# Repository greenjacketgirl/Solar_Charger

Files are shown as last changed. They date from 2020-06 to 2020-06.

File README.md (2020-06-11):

# Solar Charger Project

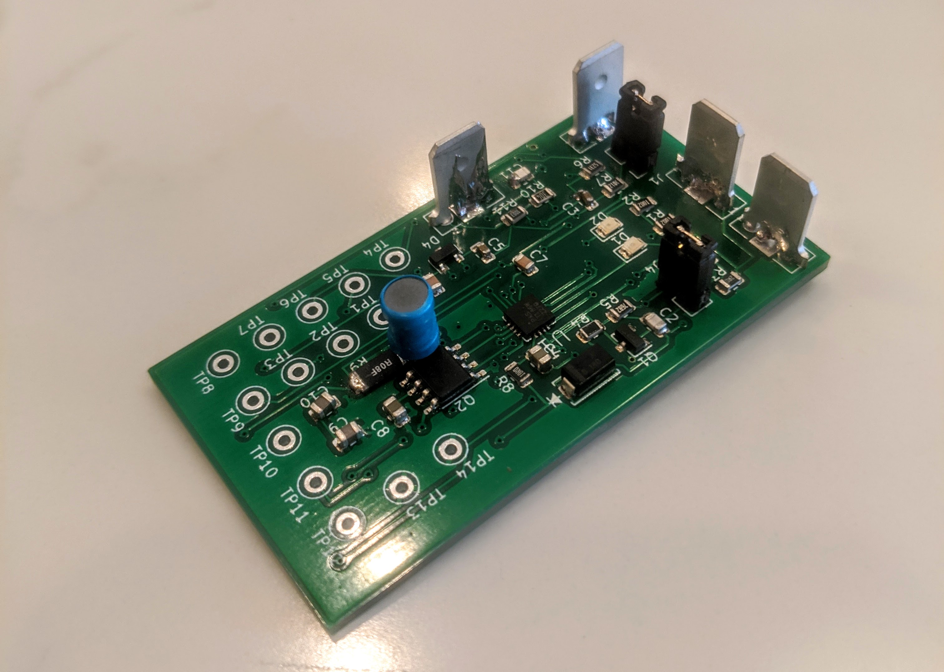
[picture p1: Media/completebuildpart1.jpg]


**Introduction** | This project was done in fullfillment of the requirments for Walla Walla University's Power Electronics class (ENGR 460) taught by [Dr. Rob Frohne](https://github.com/frohro). I chose to use Texas Instruments' BQ24650 integrated circuit as the voltage regular between a 11V solar panel and 2s 7.4V lipo. The aim was for the solar panel to charge the lipo battery at 0.5A so as to charge the battery at a standard pace while keeping the pace slow enough that the battery would not be damaged. For more details on the theory used by the charger IC, design specifications, user manual, and more - please reference the [Wiki](https://github.com/greenjacketgirl/Solar_Charger/wiki).

**Navigation** |This repository has content in the [Code](https://github.com/greenjacketgirl/Solar_Charger), [Issues](https://github.com/greenjacketgirl/Solar_Charger/issues), and [Wiki](https://github.com/greenjacketgirl/Solar_Charger/wiki) tabs.The Code section has 1 primary folder - "Solar-Charger" which contains two other folders, "Documentation" and "Kicad". The documentation folder contains stepping stone write ups and research on topics related to the issue as well as my power point presentation on the project. The Kicad folder contains the kicad files, revisions 1 and 2. Note the revisions when you are referencing them. The Wiki page contains the bulk of the documentation for this project which includes, but is not limited to the results, pcb and schematic design motives, specifiations, and objectives for the project. 

**Credits** | This project was chosen and directed by myself. However, I had professional support from my professor [Dr. Rob Frohne](https://github.com/frohro) as well as assistance from the application engineeers at texas instruments. 

**Project Status** | At the current time, the project does not fully work. While the charger circuit does not have any fried or damaged components, it does not charge the lipo battery. The STAT 1 LED turns on, indicating "charging in progress", but no charging has taken place from what I could deduce. See the [Issues](https://github.com/greenjacketgirl/Solar_Charger/issues) page for updates on current bugs.

REV 1: 05/26/2020 Build and Test Stage PART 1 | REV 2: 06/09/2020 Buil and Test Stage PART 2

***
page created by jordyn watkins | greenjacketgirl

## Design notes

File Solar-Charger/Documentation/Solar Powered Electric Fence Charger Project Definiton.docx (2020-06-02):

Solar Powered Electric Fence Charger

Project Definition: The aim of this class is to learn the basic methods of electric power analysis and design. To enforce this objective, I have chosen a project utilizing solar energy and a power switching mechanism — a solar powered electric fence charger. This project will be comprised of 2 major components:

1. Designing the solar panel voltage regulator circuit (solar to battery)
2. Designing the implementation of the electric fence (battery to fence)

The application of this project will be to provide protection for domestic animals such as chickens, from potential predators. The basic principle behind this project is using a solar panel to take in energy, which must be regulated before being directed to the input of the battery. The solar panel will be used to “top off” the charge in the battery. This battery, will then need to be attached to an inverter, which is then attached to a transformer to be bumped up to a few thousand volts (at low current levels) and modulated in pulses before transmission through the wire, thus creating an “electric fence.”

Block Diagram:

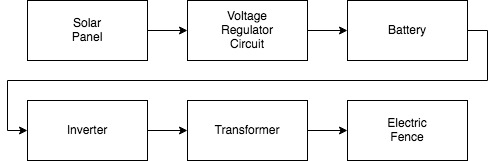
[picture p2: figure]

Upon further examination, the scope of this project definition appears to be too large. Consequently, I will be primarily focusing on the first 3 stages of this block diagram, using solar energy to maintain charge in a battery. If time permits, I will proceed to work on the last 3 blocks of the diagram, however, this remains an optional secondary goal.

A precise list of materials is yet to be determined as I develop a schematic for the voltage regulator circuit connecting the solar panel energy supply to the battery. However, a general list of parts with specifics to determine are:

- to what voltage will the energy from sunlight need to be regulated to in order to prevent damage to the battery? What minimum to charge it fully?
- What solar panel wattage/voltage will we be receiving?
- What size battery do we need to supply enough energy to the circuit/fence? 12V?
- What type of battery?
- What voltage do we need as an input to the transformer? 220V Ac?
- What voltage does our transformer need to output?
- Use of capacitors? Transistors? MOSFETS? Oscillators? Resistor Values?’ Transformer? Coils?

Resources:

http://chemelec.com/Projects/Fencer-1/Fencer-1.htm

https://www.pocketmagic.net/electric-fence-20kv/

https://www.backwoodshome.com/solar-powered-electric-fencing/

https://www.homemade-circuits.com/make-this-solar-powered-fence-charger/

https://www.homemade-circuits.com/how-to-make-solar-battery-charger/

https://www.homemade-circuits.com/how-to-build-solar-panel-voltage/

https://www.homemade-circuits.com/how-to-calculate-and-match-solar-panel/

https://www.homemade-circuits.com/how-to-make-solar-inverter-circuit/

https://gitlab.com/dakriy/solar-charger/-/wikis/theory

https://www.slideshare.net/Shubhamshekhar29/charging-of-battery-from-solar-supply-using-buck-boost-converter

https://krakkus.com/mppt-buck-boost-controller/

http://iallpowers.com/index.php?c=product&id=362

Parts List:

Lipo Battery Protection: BQ29707DSER (https://www.digikey.com/product-detail/en/texas-instruments/BQ29707DSER/296-39948-1-ND/5177825)

DataSheet: https://www.ti.com/lit/ds/symlink/bq2970.pdf

Digikey Link: https://www.digikey.com/product-detail/en/texas-instruments/BQ29707DSER/296-39948-1-ND/5177825

Cost: $0.67

MOSFET: DMG6968UDM-7

Datasheet: https://www.diodes.com/assets/Datasheets/ds31758.pdf

Digikey Link: https://www.digikey.com/product-detail/en/diodes-incorporated/DMG6968UDM-7/DMG6968UDMDICT-ND/2075462

Cost: $0.44

Boost Converter: RT4812GJ8F

Datasheet: https://www.richtek.com/assets/product_file/RT4812/DS4812-07.pdf

Digikey: https://www.digikey.com/product-detail/en/richtek-usa-inc/RT4812GJ8F/1028-1512-1-ND/5640521

Cost: $1.62

MPP: LT3652

Datasheet: https://www.analog.com/media/en/technical-documentation/data-sheets/3652fe.pdf

Digikey: https://www.digikey.com/product-detail/en/linear-technology-analog-devices/LT3652EMSE-PBF/LT3652EMSE-PBF-ND/2225686

Cost: $7.61

Jordyn WatkinsENGR460Project Definition & Research

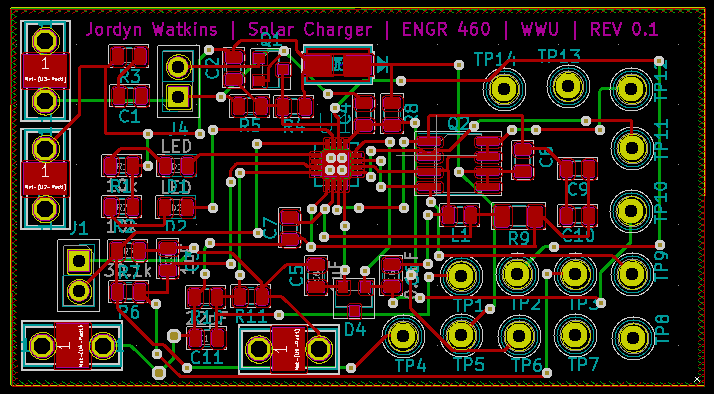
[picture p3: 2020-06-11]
Media/PCBdesign2D.png

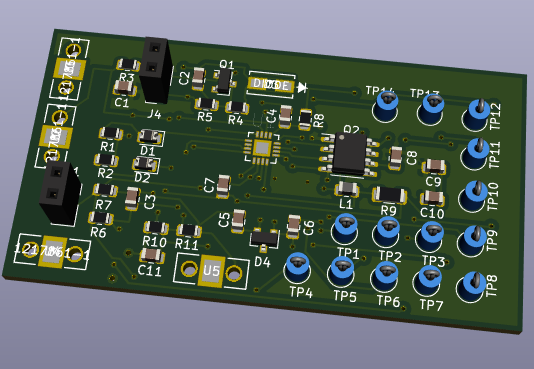
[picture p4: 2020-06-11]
Media/PCBDesign3D.png

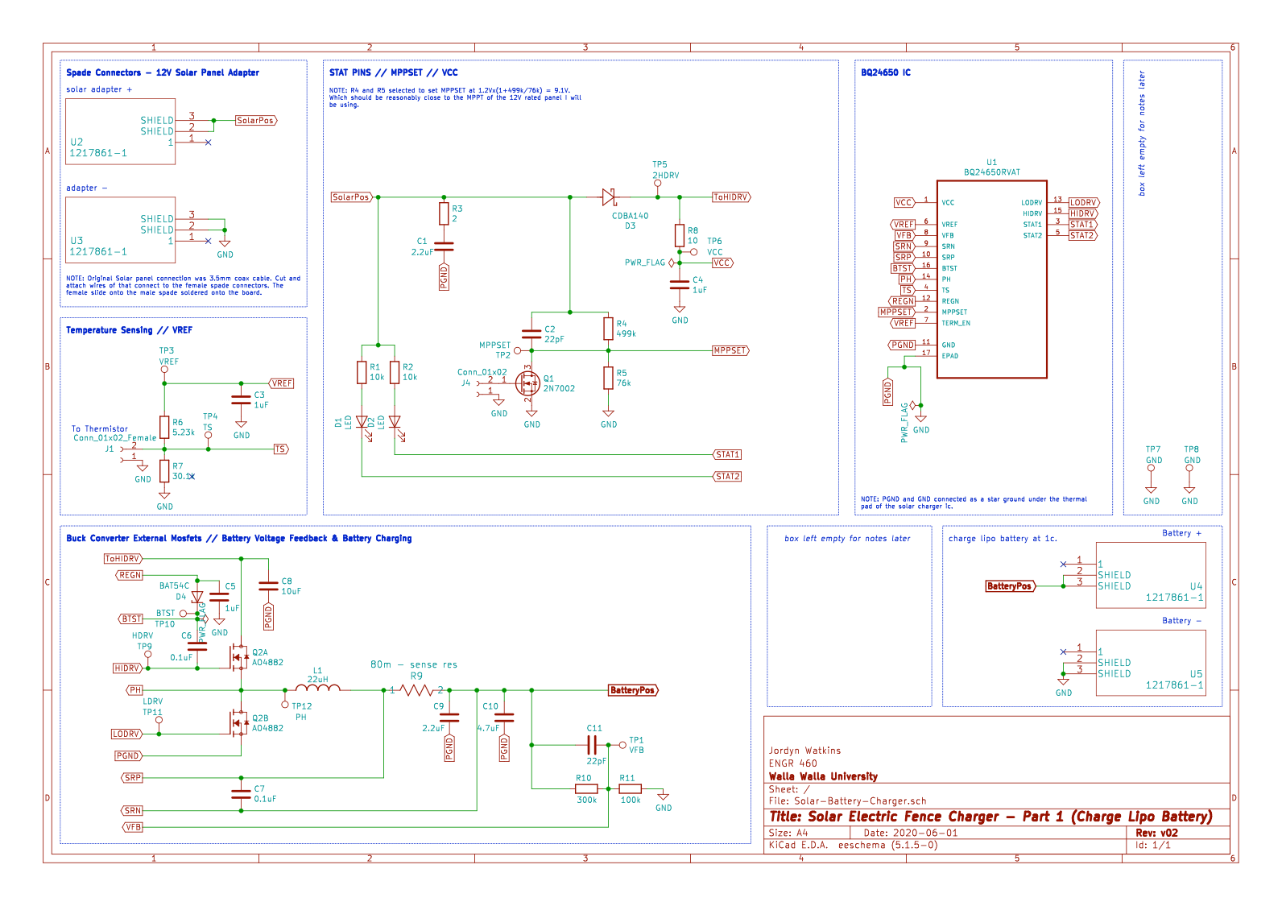
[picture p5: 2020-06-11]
Media/schematicjpg.png

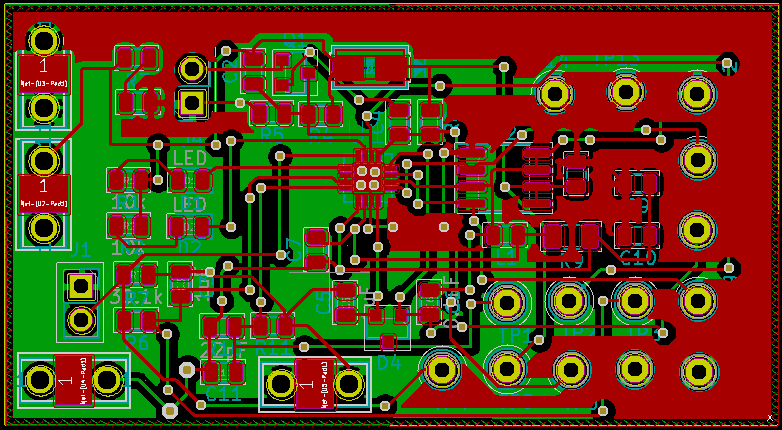
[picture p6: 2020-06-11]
Media/pcbdesigngroundlayers.png

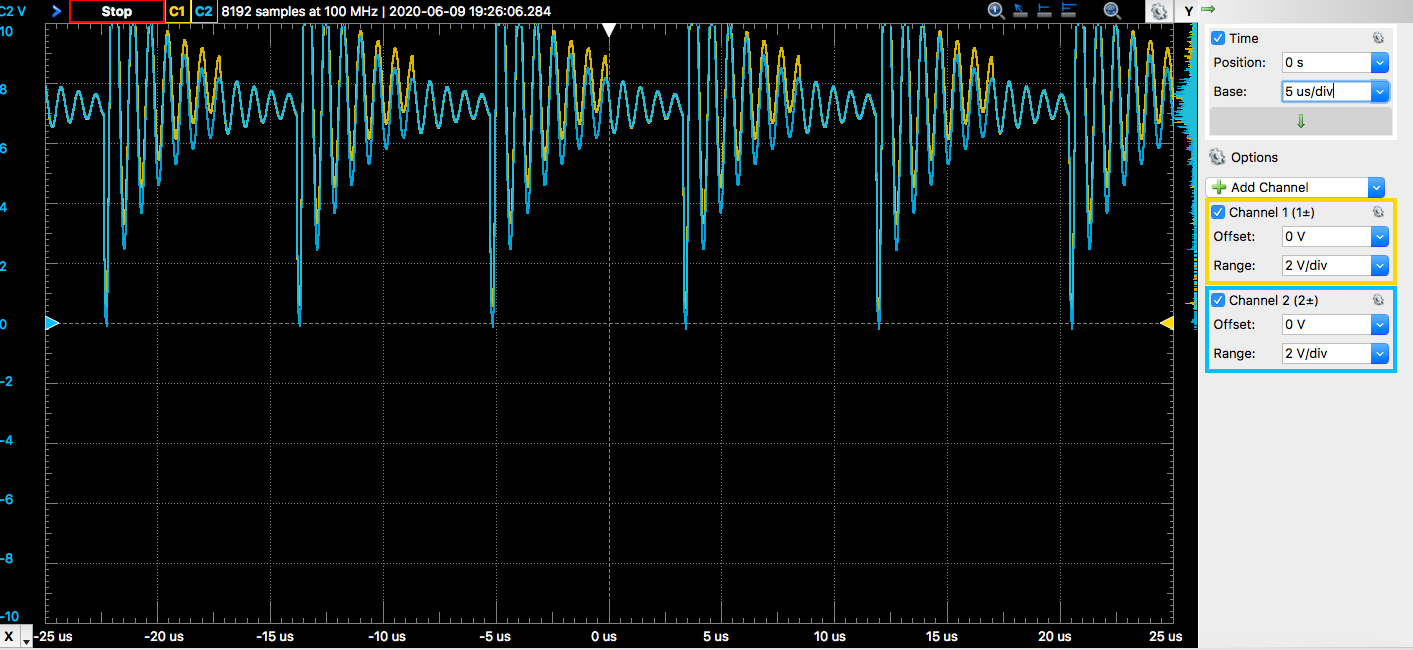
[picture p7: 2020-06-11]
Media/higdrivegateandsource.png

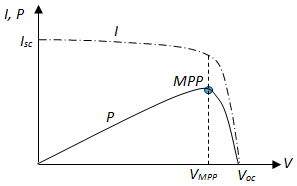
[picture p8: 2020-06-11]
Media/mpptgraphex.gif

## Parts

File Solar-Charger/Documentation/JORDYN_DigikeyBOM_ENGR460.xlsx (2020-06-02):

Manufacturer Part Number | Manufacturer | Digi-Key Part Number | Customer Reference | Reference Designator | Packaging | Part Status | Quantity | Unit Price | Extended Price | Quantity Available | Mfg Std Lead Time | Description | RoHS Status | Lead Free Status | REACH Status
RC0805FR-0710KL | Yageo | 311-10.0KCRCT-ND |  |  | Cut Tape (CT) | Active | 2 | 0.1 | $0.20 | 23427918 | 24 Weeks | RES SMD 10K OHM 1% 1/8W 0805 | ROHS3 Compliant | Lead free | REACH Unaffected
RK73B2ATTD2R0J | KOA Speer Electronics, Inc. | 2019-RK73B2ATTD2R0JCT-ND |  |  | Cut Tape (CT) | Active | 1 | 0.1 | $0.10 | 84027 | Not Available | RES 2 OHM 5% 1/4W 0805 | ROHS3 Compliant | Lead free | Not Available
RNCP0805FTD10R0 | Stackpole Electronics Inc | RNCP0805FTD10R0CT-ND |  |  | Cut Tape (CT) | Active | 1 | 0.1 | $0.10 | 44930 | 18 Weeks | RES 10 OHM 1% 1/4W 0805 | ROHS3 Compliant | Lead free | REACH Unaffected
RMCF0805FT30K1 | Stackpole Electronics Inc | RMCF0805FT30K1CT-ND |  |  | Cut Tape (CT) | Active | 1 | 0.1 | $0.10 | 27703 | 20 Weeks | RES 30.1K OHM 1% 1/8W 0805 | ROHS3 Compliant | Lead free | REACH Unaffected
RC0805FR-075K23L | Yageo | 311-5.23KCRCT-ND |  |  | Cut Tape (CT) | Active | 1 | 0.1 | $0.10 | 224777 | 24 Weeks | RES SMD 5.23K OHM 1% 1/8W 0805 | ROHS3 Compliant | Lead free | REACH Unaffected
RR1220P-304-D | Susumu | RR12P300KDCT-ND |  |  | Cut Tape (CT) | Active | 1 | 0.1 | $0.10 | 26324 | 14 Weeks | RES SMD 300K OHM 0.5% 1/10W 0805 | ROHS3 Compliant | Lead free | Not Available
RMCF0805FT100K | Stackpole Electronics Inc | RMCF0805FT100KCT-ND |  |  | Cut Tape (CT) | Active | 1 | 0.1 | $0.10 | 19612 | 20 Weeks | RES 100K OHM 1% 1/8W 0805 | ROHS3 Compliant | Lead free | REACH Unaffected
BQ24650RVAT | Texas Instruments | 296-27699-1-ND |  |  | Cut Tape (CT) | Active | 2 | 5.36 | $10.72 | 11109 | 6 Weeks | IC SYNC SW-MODE BAT CHRGR 16VQFN | ROHS3 Compliant | Lead free | REACH Unaffected
LH R974-LP-1 | OSRAM Opto Semiconductors Inc. | 475-1415-1-ND |  |  | Cut Tape (CT) | Active | 1 | 0.26 | $0.26 | 150414 | 12 Weeks | LED RED DIFFUSED 0805 SMD | ROHS3 Compliant | Lead free | REACH Unaffected
LY R976-PS-36 | OSRAM Opto Semiconductors Inc. | 475-2560-1-ND |  |  | Cut Tape (CT) | Active | 1 | 0.28 | $0.28 | 63683 | 12 Weeks | LED YELLOW DIFFUSED 0805 SMD | ROHS3 Compliant | Lead free | REACH Unaffected
C0805C106K8PACTU | KEMET | 399-4925-1-ND |  |  | Cut Tape (CT) | Active | 2 | 0.16 | $0.32 | 311400 | 13 Weeks | CAP CER 10UF 10V X5R 0805 | ROHS3 Compliant | Lead free | REACH Unaffected
C0805C475K8PACTU | KEMET | 399-3133-1-ND |  |  | Cut Tape (CT) | Active | 1 | 0.26 | $0.26 | 78213 | 13 Weeks | CAP CER 4.7UF 10V X5R 0805 | ROHS3 Compliant | Lead free | REACH Unaffected
C0805C104Z5VACTU | KEMET | 399-1177-1-ND |  |  | Cut Tape (CT) | Active | 2 | 0.1 | $0.20 | 743047 | 8 Weeks | CAP CER 0.1UF 50V Y5V 0805 | ROHS3 Compliant | Lead free | REACH Unaffected
C0805C220J5GACTU | KEMET | 399-1113-1-ND |  |  | Cut Tape (CT) | Active | 2 | 0.1 | $0.20 | 684505 | 8 Weeks | CAP CER 22PF 50V C0G/NP0 0805 | ROHS3 Compliant | Lead free | REACH Unaffected
WSL2010R0800FEA18 | Vishay Dale | WSLF-.08CT-ND |  |  | Cut Tape (CT) | Active | 1 | 1.06 | $1.06 | 12135 | 20 Weeks | RES 0.08 OHM 1% 1W 2010 | ROHS3 Compliant | Lead free | Not Available
C0805C225Z4VACTU | KEMET | 399-1295-1-ND |  |  | Cut Tape (CT) | Active | 2 | 0.21 | $0.42 | 142901 | 8 Weeks | CAP CER 2.2UF 16V Y5V 0805 | ROHS3 Compliant | Lead free | REACH Unaffected
CDBA140-G | Comchip Technology | 641-1015-1-ND |  |  | Cut Tape (CT) | Active | 1 | 0.33 | $0.33 | 276700 | 12 Weeks | DIODE SCHOTTKY 40V 1A DO214AC | ROHS3 Compliant | Lead free | REACH Unaffected
AO4882 | Alpha & Omega Semiconductor Inc. | 785-1317-1-ND |  |  | Cut Tape (CT) | Active | 1 | 0.61 | $0.61 | 5270 | 18 Weeks | MOSFET 2N-CH 40V 8A 8SOIC | ROHS3 Compliant | Lead free | REACH Unaffected
2N7002LT1G | ON Semiconductor | 2N7002LT1GOSCT-ND |  |  | Cut Tape (CT) | Active | 1 | 0.18 | $0.18 | 894580 | 6 Weeks | MOSFET N-CH 60V 0.115A SOT-23 | ROHS3 Compliant | Lead free | REACH Unaffected
BAT54CQ-7-F | Diodes Incorporated | BAT54CQ-7-FDICT-ND |  |  | Cut Tape (CT) | Active | 1 | 0.21 | $0.21 | 4063 | 14 Weeks | SCHOTTKY DIODE SOT23 | ROHS3 Compliant | Lead free | REACH Unaffected
1217861-1 | TE Connectivity AMP Connectors | A100452CT-ND |  |  | Cut Tape (CT) | Active | 4 | 0.11 | $0.44 | 300446 | 4 Weeks | CONN QC TAB 0.250 SOLDER | ROHS3 Compliant | Lead free | REACH Unaffected
PMEG4050EP,115 | Nexperia USA Inc. | 1727-5842-1-ND |  |  | Cut Tape (CT) | Active | 1 | 0.42 | $0.42 | 56677 | 4 Weeks | DIODE SCHOTTKY 40V 5A SOD128 | ROHS3 Compliant | Lead free | REACH Unaffected
ERA-6AEB4993V | Panasonic Electronic Components | P499KDACT-ND |  |  | Cut Tape (CT) | Active | 1 | 0.34 | $0.34 | 41139 | 12 Weeks | RES 499K OHM 0.1% 1/8W 0805 | ROHS3 Compliant | Lead free | REACH Unaffected
RC0805FR-0776K8L | Yageo | 311-76.8KCRCT-ND |  |  | Cut Tape (CT) | Active | 1 | 0.1 | $0.10 | 243656 | 24 Weeks | RES SMD 76.8K OHM 1% 1/8W 0805 | ROHS3 Compliant | Lead free | REACH Unaffected
SBC1-220-132 | KEMET | 399-20736-ND |  |  | Bulk | Active | 1 | 0.88 | $0.88 | 479 | 27 Weeks | FIXED INDUCTOR 22UH 1.3A 130MOHM | ROHS3 Compliant | Lead free | Not Available
744045220 | Würth Elektronik | 732-3074-1-ND |  |  | Cut Tape (CT) | Active | 1 | 0.8 | $0.80 | 2522 | 12 Weeks | FIXED IND 22UH 630MA 700 MOHM | ROHS3 Compliant | Lead free | REACH Unaffected

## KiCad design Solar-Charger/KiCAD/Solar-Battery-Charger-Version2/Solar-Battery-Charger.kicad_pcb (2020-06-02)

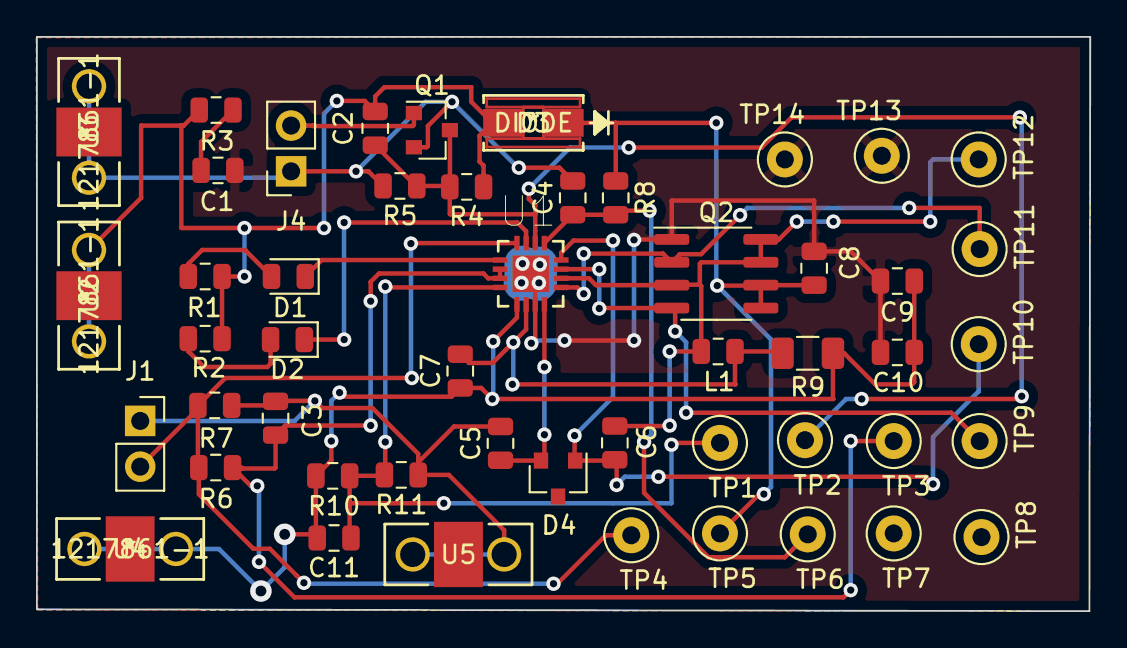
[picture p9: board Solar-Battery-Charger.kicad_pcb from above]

Board: 2 copper layers, 58.5 x 31.9 mm, 50 parts (0 on the bottom side), 21 nets.

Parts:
C1, C9: 2.2uF; C_0805_2012Metric
C2, C11: 22pF; C_0805_2012Metric
C3, C4, C5: 1uF; C_0805_2012Metric
C6, C7: 0.1uF; C_0805_2012Metric
C8: 10uF; C_0805_2012Metric
C10: 4.7uF; C_0805_2012Metric
D1, D2: LED; D_0805_2012Metric
D3: DIODE; CDBA140-G
D4: D_Zener; SOT-23
J1, J4: Conn_01x02_Female; PinSocket_1x02_P2.54mm_Vertical
L1: 22uH; L_0805_2012Metric
Q1: 2N7002; SOT-23
Q2: SI7288DP-T1-GE3; SOIC-8_3.9x4.9mm_P1.27mm
R1, R2: 10k; R_0805_2012Metric
R3: 2; R_0805_2012Metric
R4: 499k; R_0805_2012Metric
R5: 76k; R_0805_2012Metric
R6: 5.23k; R_0805_2012Metric
R7: 30.1k; R_0805_2012Metric
R8: 10; R_0805_2012Metric
R9: 80m - sense res; R_1206_3216Metric
R10: 300k; R_0805_2012Metric
R11: 100k; R_0805_2012Metric
TP1, TP2, TP3, TP4, TP5, TP6, TP7, TP8, TP9, TP10, TP11, TP12, TP13, TP14: TestPoint; TestPoint_Loop_D1.80mm_Drill1.0mm_Beaded
U1: BQ24650RVAT; QFN50P350X350X100-17N
U2, U3, U4, U5: 1217861-1

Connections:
BTST: C6.1, D4.1, TP10.1, U1.16
HIDRV: Q2.4, TP9.1, U1.15
LODRV: Q2.2, TP11.1, U1.13
MPPSET: C2.2, Q1.3, R4.2, R5.1, TP2.1, U1.2
unnamed: C1.1, R3.2
unnamed: C2.1, D3.2, R1.2, R2.2, R3.1, R4.1, U2.2, U2.3
unnamed: C3.1, R6.1, TP3.1, U1.6, U1.7
unnamed: D1.2, R1.1
unnamed: D2.2, R2.1
unnamed: J1.2, R6.2, R7.1, TP4.1, U1.4
unnamed: J4.2, Q1.1
PGND: C1.2, C3.2, C4.2, C5.2, C8.2, C9.1, C10.1, J1.1, J4.1, Q1.2, Q2.1, R5.2, R7.2, R11.1, TP7.1, TP8.1, TP13.1, TP14.1, U1.11, U1.17, U3.2, U3.3, U5.2, U5.3
PH: C6.2, L1.1, Q2.3, Q2.7, Q2.8, TP12.1, U1.14
REGN: C5.1, D4.2, U1.12
SRN: C7.1, C9.2, C10.2, C11.2, R9.2, R10.2, U1.9, U4.2, U4.3
SRP: C7.2, L1.2, R9.1, U1.10
STAT1: D2.1, U1.3
STAT2: D1.1, U1.5
ToHIDRV: C8.1, D3.1, Q2.5, Q2.6, R8.1, TP5.1
VCC: C4.1, R8.2, TP6.1, U1.1
VFB: C11.1, R10.1, R11.2, TP1.1, U1.8

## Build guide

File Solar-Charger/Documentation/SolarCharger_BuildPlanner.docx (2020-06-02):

Solar Charger Project: Build Planner

Following this build planner will decrease the probability of frying components in the circuit board, thus increasing chances of a successful, working project.

PREP-STAGE

- Prepare outline for report
  - Should include procedure for testing
  - Documentation of test results
  - Include dates
  - Include pictures, screenshots of simulations
- Prepare toaster oven for soldering
  - Test with a board with a few extra resistors or something to make sure that it will get hot enough and doesn’t get too hot.

STAGE 1 – Construction of Board

- Document Parts

Part | Quantity | Theoretical Value | Actual Value | Notes
RES SMD 10K OHM 1% 1/8W 0805 | 2 | 10kΩ
RES 2 OHM 5% 1/4W 0805 | 1 | 2Ω
RES 10 OHM 1% 1/4W 0805 | 1 | 10Ω
RES 30.1K OHM 1% 1/8W 0805 | 1 | 30.1kΩ
RES SMD 5.23K OHM 1% 1/8W 0805 | 1 | 5.23kΩ
RES SMD 300K OHM 0.5% 1/10W 0805 | 1 | 300kΩ
RES 100K OHM 1% 1/8W 0805 | 1 | 100kΩ
IC SYNC SW-MODE BAT CHRGR 16VQFN | 2 | --
LED RED DIFFUSED 0805 SMD | 1 | --
LED YELLOW DIFFUSED 0805 SMD | 1 | --
CAP CER 10UF 10V X5R 0805 | 2 | 10uF
CAP CER 4.7UF 10V X5R 0805 | 1 | 4.7uF
CAP CER 0.1UF 50V Y5V 0805 | 2 | 0.1uF
CAP CER 22PF 50V C0G/NP0 0805 | 2 | 22pF
RES 0.08 OHM 1% 1W 2010 | 1 | 0.08Ω
CAP CER 2.2UF 16V Y5V 0805 | 2 | 2.2uF
DIODE SCHOTTKY 40V 1A DO214AC | 1 | --
MOSFET 2N-CH 40V 8A 8SOIC | 1 | --
MOSFET N-CH 60V 0.115A SOT-23 | 1 | --
SCHOTTKY DIODE SOT23 | 1 | --
CONN QC TAB 0.250 SOLDER | 4 | --
DIODE SCHOTTKY 40V 5A SOD128 | 1 | --
RES 499K OHM 0.1% 1/8W 0805 | 1 | 499kΩ
RES SMD 76.8K OHM 1% 1/8W 0805 | 1 | 76.8kΩ
FIXED INDUCTOR 22UH 1.3A 130MOHM | 1 | 22uH
PCB | 5 | --

List of Extra Parts

- Examine PCB board for visible shorts – compare to Kicad schematic, and PCB design
- Examine Solder Paste Stencil for cut errors
- Apply solder paste
- Place SMD components
- Place in toaster oven and watch the magic happen!
  - Look for the solder paste to draw together on the pads and appear shiny
  - Should only take a few minutes
- Solder on remaining through hole components and correct pieces that did not set properly
- Examine all solder joints for good connections (use magnifying glass) and check for misconnections via multimeter if unsure
- Attach connectors that enable connection to the solar panel and lipo battery
- Double check that the solar panel still outputs 11 volts
- Check for power shorts!
  - Make GND and PGND are NOT shorted together. If they are, NO BUENO. Proceed to a lot of trouble shooting and looking at schematics. Then use exacto knife and extra wire as necessary to fix connection.
    - GND – TP 7,8
    - PGND – TP 13,14
  - Make sure VCC pin on Texas Instruments IC is NOT shorted to any GND or PGND.
- Triple check that MOSFETS are in correct orientation, and diodes are in correct orientation.
- Look into possible installation of a fuse at the output to battery to monitor current (I created larger sized vias in the correct place where I can install the fuse and cut the trace)
- Hook the board up to a constant voltage source first (diligent discovery analyzer), send constant voltage of 11V into board
  - Monitor input voltage at TP 5 and TP 6 to the VCC pin make sure that it is between -0.3V and 33V (so it doesn’t fry the IC – because that would be very bad)
  - Look at MPPSET – TP2. Make sure that it is set to 1.2V
  - Verify the battery is charging at 8.4V, with a current less than 1 A (hopefully 0.5A) TP1
  - Check Battery charge to see if it’s charging.
    - Monitor how fast it takes to charge the 2S lipo.
- If everything checks out with the 11V constant voltage, then proceed to replace that input voltage with the solar panel. –check all the same criteria as above
  - Document how long it takes to charge the battery with the panel
  - Compare the rate of charge with that of the constant voltage source
    - Consider – do I need to have an input current source in addition to voltage source? Check with Dr. Frohne and classmates.
- Use other test points to monitor all the inputs and outputs of the texas instruments IC to double check for consistency with the data sheet.
- If it doesn’t work, read through data sheet again carefully. Note voltage maximums and minimums, current maximums and minimums, and temperature maximums. Check for burnt out components (as this will give a clue to where the issue occurred) and replace if possible.

Notes on Testing Process

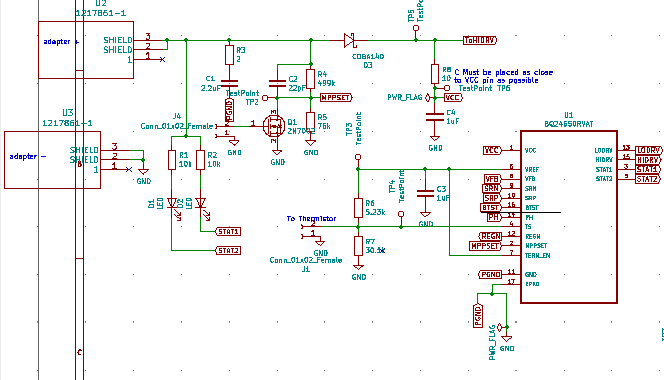
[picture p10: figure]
../../../../Dropbox/Screenshots/Screenshot%202020-05-18%2000.49.29.p
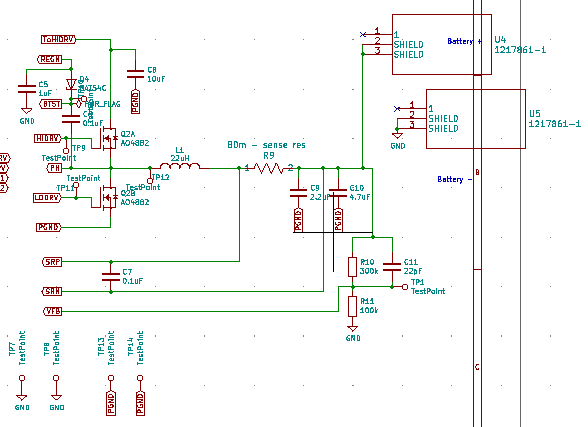
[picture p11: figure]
../../../../Dropbox/Screenshots/Screenshot%202020-05-18%2000.49.49.p
../../../../Dropbox/Screenshots/Screenshot%202020-05-18%2000.52.10.p
../../../../Dropbox/Screenshots/Screenshot%202020-05-18%2000.50.45.p

Jordyn Watkins ENGR 46005/18/2020

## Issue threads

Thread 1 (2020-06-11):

Trace Burned

greenjacketgirl, 2020-06-11:
### Background
The board was completely built. I tested the continuity between pads based on the kicad schematic, and I made sure to test the continuity between VCC and GND was zero.
### Description of Issue
I attached the lipo battery to the solar charger circuit (without the solar panel attached). Theoretically, this would imply that the charger is in its "SLEEP" mode. There shouldn't be any path from the Battery positive terminal to GND, theoretically. However, connecting the battery resulted in a whisper of smoke escaping from a trace on my board within milliseconds of connecting the battery.
Photo of board with fried trace attached
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

greenjacketgirl, 2020-06-11:
### Solution - ish
I hoped that the only thing that was damaged was the trace - maybe too optimistically hoping it worked as a built in fuse of sorts. So, I replaced the trace with an LED, thinking that the extra layer of protection would be a good idea.
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

I could now attach the battery without anything else going up in smoke.

Closed 2020-06-11.

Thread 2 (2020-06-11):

LODRV Mosfet Fried

greenjacketgirl, 2020-06-11:
### Background
Previously, I had hoped that only component in my circuit that had fried from the battery discharge was the trace. Unfortunately, I was wrong.

### Description of Issue
After discussing the issue with Dr. Frohne, he mentioned that it was highly likely that the current was able to go somewhere before the trace burned. Looking at the schematic, it appeared that the only possible place for the current to go was through the mosfet. Per his suggestion, I tested the mosfet, first in the circuit to see if there was any suspicious behavior - which unfortuantely there was. To confirm our suspicion, I removed the mosfet and tried testing it again.  Sadly, the mosfet was not in good shape. The LODRV Mosfet was shorted.
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

greenjacketgirl, 2020-06-11:
### Solution
I inquired with the application engineer at Texas Instruments on the E2E help forum for suggestions on why  the Mosfet fried. He suggested that I had the direction of the body diode of the mosfet flipped, so that the battery now had a path to GND. But after checking the schematic, datasheet for pinouts, PCB design, and actual board - I concluded that I did not have the mosfet switched the wrong way.

Further hypothesizing suggested that maybe, since it is an electrostatic sensitive part, that I had damaged it before I ever put it on the board. Continuing to ponder over why the mosfet fried, I proceeded to order new mosfets to replace the one that was damaged.

greenjacketgirl, 2020-06-11:
https://e2e.ti.com/support/power-management/f/196/p/910502/3373256#3373256

Closed 2020-06-11.

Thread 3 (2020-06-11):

Unusual Voltages for REGN and VREF

greenjacketgirl, 2020-06-11:
### Background
At this point and time, my new Mosfets have arrived, and I have soldered it back onto the board. The protection LED I added is still present.

### Description of Issue
The characteristic voltages that I measured have not changed even though I replaced the mosfet. The measured voltages are as follows:

| Test Point                              | Voltage Reading |
|-----------------------------|----------------- |
| Vsolar                                    | 10.34V                 |
| VCC                                       | 10.28V                 |
| ToHIDRV                                | didn't record       |
| TS                                          | 4.4V                     |
| VREF                                      | 5.16V                   |
| REGN                                     | 1.66V                   |
| BTST                                      | 1.8V                     |
| HIDRV                                    | 0V                        |
| LODRV                                   | 1.605V                 |
| VFB                                        | 1.26V                   |
| SRN                                        | 1.589V                |
| SRP                                        | 1.595V                 |
| PH                                          | 1.623V                 |
| Vbat-Start                              | didn't record       |
| Vbat-End (30 minutes later) | didn't record       |

The problem is that VREF and REGN are supposed to be fixed voltages output by the IC. Based on the datasheet, they are supposed to read 3.3V and 6V respectively. But this is not what my readings said.

greenjacketgirl, 2020-06-11:
### Solution
In search of a solution, I reached out again to the texas instruments application engineer on the E2E forum. He said that yes, it was very problematic with the readings I was getting. So I concluded that my charging IC was fried.

greenjacketgirl, 2020-06-11:
https://e2e.ti.com/support/power-management/f/196/p/910502/3373256#3373256

Closed 2020-06-11.

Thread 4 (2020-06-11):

Charger IC Fried

greenjacketgirl, 2020-06-11:
### Background

### Description of Issue

greenjacketgirl, 2020-06-11:
### Solution
I had ordered a second charger IC just in case, but did not order duplicates of anything else. So I needed to desolder each component from the old board one at a time and then resolder it to the new board. So that's what I did. The new board was identical to the first revision with the exception that I no longer had the extra LED in there as protection. I double checked all the connections to make sure they were only connected where they were supposed to be, then I checked specifically Battery positive to GND with both the continuity test and with the diode test on the multi-meter. I found that it was 0L with the positive lead on the battery and negative on ground. Switching the polarity of leads, I got a diode drop of 0.56V. Which corresponds nicely to the drop expected in the body diode of the LODRV mosfet.

With these preliminary tests done, I connected the solar panel and voila! Nothing burned yet! AND VREF and REGN were at 3.27V and 5.95V respectively - matching what I anticpated from the datasheet.

Closed 2020-06-11.

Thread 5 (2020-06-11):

Lipo Battery Not Charging

greenjacketgirl, 2020-06-11:
### Background

### Description of Issue

greenjacketgirl, 2020-06-11:
Talking to the application engineers at Texas Instruments again, they suspect that the issue may be due to the layout of my board... This is still to be investigated.

greenjacketgirl, 2020-06-11:
https://e2e.ti.com/support/power-management/f/196/p/910502/3373256#3373256

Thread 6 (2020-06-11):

Forgot to order 0.1uF capacitors

greenjacketgirl, 2020-06-11:
### Background
The first issue I encountered with this project was actuallly regarding parts.

### Description of Issue
I had completely forgotten to order 0.1uF capacitors. So I had 3 capacitors missing. Fortunately, they were all used as bypass capacitors, so the exact value of them was not  as crucial as if it was part of a circuit.

greenjacketgirl, 2020-06-11:
### Solution
I had one extra 10uF capacitor, so I used this one to replace the 0.1uF that was supposed to be near the VCC of the IC. However, I still had two others missing. Thankfully, I had some extra circuit boards lying around. I was able to test the capacitance of the 0805 components on the board and was able to desolder them from the old board and transfer them to this project's board.

Closed 2020-06-11.

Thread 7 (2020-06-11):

TS pin inhibiting charge

greenjacketgirl, 2020-06-11:
### Background
I have now moved everything to a new board. The IC outputs the correct voltages and when I attach the battery, nothing goes up in smoke anymore! Frankly, I was never able to figure out what happened the first to cause the circuit to short. It's possible that there was a bridge between LODRV and PH that I couldn't see somewhere - possibly beneath the IC where it was impossible for me to check for bridges. But I checked the pins farther form the IC and it didn't indicate that there were any bridges. So I concluded that MOSFET actually stands for "Magically Obliterated Smoke and Fire Emitting Transistor".

### Description of Issue
The issue was that the battery wasn't charging. But it also became evident that I had the incorrect TS resistor divider.  I was essentially defaulting the charger into SLEEP mode.

greenjacketgirl, 2020-06-11:
### Solution
I remedied this issue by changing my resistor values around so that I had a TS voltage of 2V. Which was quite close to the middle range of the active charging state for the IC. The IC would charge only if the TS pin was between VLTF and VHTF. Where VLTF corresponded to 73.5% of the voltage on VREF, and VHTF corresponded to 47.5% of the voltage on VREF. Given that VREF was 3.3V, then VLTF = 2.4V and VHTF = 1.56V. So my selected resistors to set it at 2V rectified the issue.

Now, when I plugged in the solar panel, the STAT1 LED turned on! Indicating that charge was in progress.

Closed 2020-06-11.

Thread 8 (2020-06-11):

STAT1 LED on even when the battery is not connected

greenjacketgirl, 2020-06-11:
### Background
The STAT1 and STAT2 pins on the IC are used to help the user figure out what the charger IC is doing and what state it is in.
STAT1 LED on, STAT2 LED off == charging in progress
STAT1 LED off, STAT2 LED on == charging complete
STAT1 LED off, STAT2 LED off == SLEEP mode or some other fault.

### Description of Issue
The STAT1 pin should only light up when all the charging criteria are met, and this include a battery detection function. So the question arises - why is the LED coming on even when a battery is not attached?

shridattdudhat, 2020-07-02:
The same thing happens to my board... I have designed board in Eagle CAD, I think maybe the issue with the layout I am not sure... Please suggest if you find some solution.

This is my layout and schematic screenshot:

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

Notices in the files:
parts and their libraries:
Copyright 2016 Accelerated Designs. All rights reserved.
